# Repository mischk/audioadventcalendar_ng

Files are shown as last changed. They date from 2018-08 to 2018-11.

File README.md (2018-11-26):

# audioadventcalendar_ng

This will be the new version of the Audio Adventcalendar I made in 2011. It uses an JQ6500 mp3 module instead of the waveshield, which makes the code much more easier and readable and makes the whole circuit much smaller if using an Arduino Nano instead of the UNO.

----

There are some minor mistakes in the instructions. I'll collect them here, so you can build without hassleling...

* Folder Structure:
  as mentioned by [Landixus](https://github.com/Landixus) ([Issue #3](https://github.com/mischk/audioadventcalendar_ng/issues/3)) the folder structure on the sd-card must be like: /00/0xx.mp3.
  Folder Name is 00 NOT 000.

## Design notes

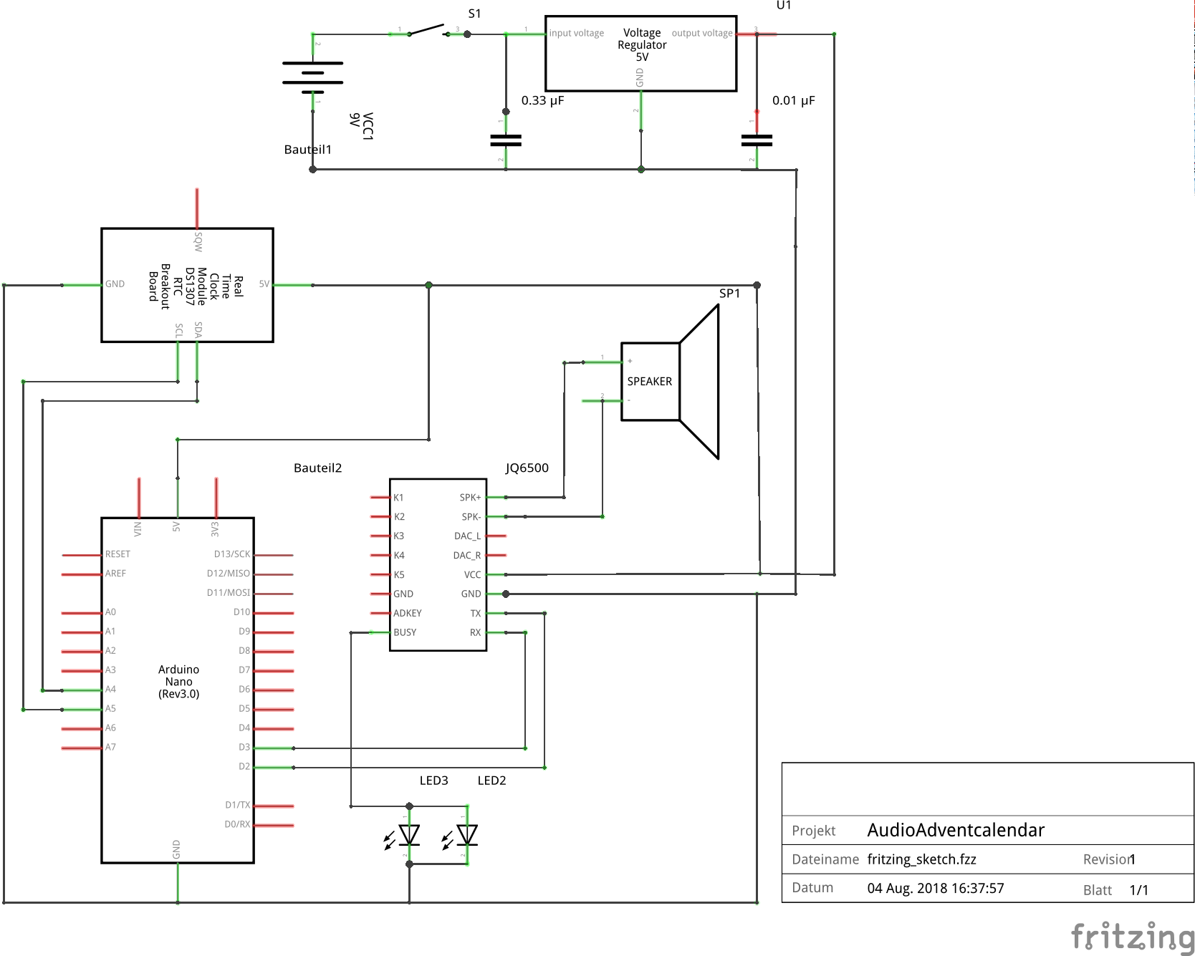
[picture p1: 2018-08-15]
fritzing_sketch_Schaltplan.png

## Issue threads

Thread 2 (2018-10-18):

Schaltplan

htyx75, 2018-10-18:
Moin aus Hamburg,
ich finde Deine Idee super und würde das für meine Kids gerne nachbauen.
Gibt es die Möglichkeit, dass Du mir den genauen Schaltplan zusendest?

Gruss

Henrik

Landixus, 2018-10-31:
Schaltplan findet man hier:
https://www.heise.de/make/artikel/Statt-Schokolade-Audio-Adventskalender-zum-Selberbauen-4157308.html

RcTomcat1, 2018-10-31:
Der ist nur leider falsch......
da fehlt ein 1kohm Wiederstand zwischen RX und D3. Ohne den ist der JQ6500 direkt nach dem einschalten Elektroschrott......Musste ich leider soeben auf die harte Tour lernen

lotte67890, 2018-10-31:
Bist du sicher dass es ein 1kohm WIderstand ist? Wenn ich den Farbcode halbwegs erkennen kann würde ich sagen 3.7kohm oder 4kohm...

RcTomcat1, 2018-10-31:
Steht zumindest so in der JQ6500 Serial Doku
https://github.com/sleemanj/JQ6500_Serial
To use this library with a 5v Arduino, connect as follows.
JQ6500 Module | Arduino
-- | --
RX | through a 1K Resistor then to pin 9
TX | pin 8
GND (any of) | GND
VCC (any of) | VCC

Ich sehe in dem einen Bild Gelb, Violet, Rot, Gold. Das wäre ein 4,7K Ohm oder?

lotte67890, 2018-10-31:
Yepp, das wären 4.7k, ich bin mir nur unschlüssig ob der "erste" Ring gelb oder Orange ist.. Allerdings wären 3.7k relativ unüblich... Andererseits, je höher desto weniger geht beim Versuch kaputt... Kann höchstens sein dass es nicht funktioniert...

RcTomcat1, 2018-10-31:
Also ohne Wiederstand funktioniert es nur ganze 5 Sekunden XD. Hoffe mal Ich hab mein JQ6500 nicht geröstet.....
Habe mal 3,7 und 4,7K ohm bestellt und werde testen. Ersatz für den JQ ist auch bestellt, dauert halt wieder 3 Wochen. Könnte gerade so klappen mit Dezember

htyx75, 2018-10-31:
Laut Author wird kein Widerstand benötigt.
Da im Manual einer genannt wird, sollte da unbedingt ein 1k Widerstand hin.

sent from my iPhone

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

Landixus, 2018-10-31:
Ich hab keine Probleme ohne Widerstand, benutze den 28p.
Aber ich denke 1k sollten langen.
Hab zum Glück Reichelt um die Ecke, das ist gut wenn man schnell was braucht, ausser am Feiertag :)

RcTomcat1, 2018-10-31:
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

Hm ok, mein 28p hat eben nur 5 Sekunden was getan und dann war tot.
Kein Busy Signal mehr und damit keine LEDs, kein Sound.

htyx75, 2018-10-31:
Ich hab den JQ6500 bei AliExpress bestellt. Hat keine zwei Wochen gedauert.

sent from my iPhone

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

lotte67890, 2018-10-31:
Noch ne Frage, laut Schaltplan wird ein 0,01uf Kondensator an den 5v Ausgang angeschlossen, ich finde aber keinen... 0,1uf wäre verfügbar... sollte der auch funktionieren?

Landixus, 2018-11-01:
Der ist nur zum glätten, ich würde den bei einer Batterie weg lassen.

mischk, 2018-11-26:
Ich habe das ohne Widersand verschaltet, und er läuft ohne Probleme. Aber es schadet auf keinen Fall einen einzubauen.

Closed 2018-12-27.

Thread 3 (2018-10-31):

I have an issue with the folder structure

Landixus, 2018-10-31:
I cannot not figured out the folder structure.
What i need to do exact on the sd card?

With the example i can play mp3 from the JQ6500
But with your code i have no play. It says Playing in serial Monitor:
Audio Advent Calendar by Mischka

playing track Number: 20

I have tried a folder "000" wit a mp3file  "020.mp3" in the folder, but it will not play the sound!?
Have you an idea?

Landixus, 2018-10-31:
Ok solved it.
The instructions in Heise.de is not correct for the Folder.
You need to have following Structure:
"Folder" 00
"MP3_Item" 020

mischk, 2018-11-26:
thank you!

Closed 2018-11-26.

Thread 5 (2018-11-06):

Clock Modul do not count

Landixus, 2018-11-06:
I have the problem that the DS3231 always on the same day.
Any other have this issue?

Oldbadbear, 2018-11-07:
I think the Code must be modified in the following way:

  if (! RTC.isrunning()) {
    Serial.println("RTC is NOT running!");
    // following line sets the RTC to the date & time this sketch was compiled
    RTC.adjust(DateTime(__DATE__, __TIME__));
  }

Oldbadbear, 2018-11-08:
Perhaps you need to remove the Battery and Power form DS3231 before compiling the Code, so the rtc is stopped.
Eventually the code must be improved to test the Time and set it, if it is not right.

Landixus, 2018-11-08:
I have set the time with another script, then i haved loaded the adventcalendar script. When i am home from work i check the magic :) I check your forked project. Thanks a lot!

ThBe123, 2018-11-20:
Hello Landixus,
which script exactly did you use to set the RTC Clock?
thx ThBe

Landixus, 2018-11-20:
> Hello Landixus,
> which script exactly did you use to set the RTC Clock?
File > Examples > DS 1307 > SetTime

ThBe123, 2018-11-23:
Thank you for your answer.
I managed to set the RTC but if i disconnect the Nano from my PC he is losing the Date/Time again (Yes, battery is attached and ok).
Will the code from Oldbadbear fix that problem?
Thx

Landixus, 2018-11-25:
> Will the code from Oldbadbear fix that problem?
> Thx
// setup rtc
  Wire.begin();
  rtc.begin();
   if (! rtc.isrunning()) {
   Serial.println("RTC is NOT running!");
   // following line sets the RTC to the date & time this sketch was compiled
   rtc.adjust(DateTime(__DATE__, __TIME__));
 }
 // rtc.adjust(DateTime(__DATE__, __TIME__));

ThBe123, 2018-11-26:
:-D
Thx ... its working!!!

mischk, 2018-11-26:
So, what code did the magic for you? In my case its working correctly.

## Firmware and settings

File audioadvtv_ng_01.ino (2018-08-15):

// Audio Advent Calendar
// (c) by Mischka 2011-2018 (mischka@mailbox.org)
// Licensed under CC0

// feel free to optimize and modify the code, please share your
// mods on the internet and send me a mail with the link

// V 0.2: code is basically working
// V 0.3: code works like expected
  

/* Todo:
  - add more comments for make readers
  */ 

#include <JQ6500_Serial.h>
#include <SoftwareSerial.h>
#include <Wire.h>
#include "RTClib.h"

JQ6500_Serial mp3(2,3); //create an mp3 object
RTC_DS1307 rtc;         //create an rtc object

void setup() {
  Serial.begin(57600);
  Serial.println("Audio Advent Calendar by Mischka");
  Serial.println("----");
  
  pinMode(4, INPUT);
  pinMode(13, OUTPUT);

// setup the mp3 module 
  mp3.begin(9600);
  mp3.reset();
  delay(500);
  mp3.setVolume(22);
  mp3.setLoopMode(MP3_LOOP_NONE);

// setup rtc
  Wire.begin();
  rtc.begin();
  rtc.adjust(DateTime(__DATE__, __TIME__));
}

void loop() {
  
  DateTime now = rtc.now();
  
  if(mp3.getStatus() != MP3_STATUS_PLAYING) {
    if (now.day() < 25){
      if (now.month() == 12) {

        Serial.print("playing track Number: ");
        Serial.println(now.day());

        mp3.playFileNumberInFolderNumber(0, now.day());      
      }
      else{
        Serial.println("not an advent day");
        delay(100);
        exit(0);
      }
    }
  }
exit(0);  
}

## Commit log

2018-08-04 added schematics (fritzing sketch)
    [fritzing_sketch.fzz]
2018-08-04 cleared out some bugs, finished code so far
    [audioadvtv_ng_01.ino]
2018-08-04 added LEDs
    [fritzing_sketch.fzz]
